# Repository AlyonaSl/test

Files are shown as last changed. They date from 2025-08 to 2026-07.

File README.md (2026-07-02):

# Label roll holder — 3D-printable, parametric

A slim, industrial-looking desk-edge holder for **3 label rolls**.

Two parametric implementations are provided for the same product:

1. **`LabelHolder.scad`** — OpenSCAD model (primary), exports `STL` + `3MF` +
   `STEP`. See **[OpenSCAD model](#openscad-model-labelholderscad)** below.
2. **`src/label_roll_holder.py`** — CadQuery/Python variant (analytic BREP
   `STEP`), documented in the rest of this file.

---

## OpenSCAD model (`LabelHolder.scad`)

Desk-edge clamp whose stand carries the axle at the **centre of its length**, so
the Ø16 mm axle extends to both sides and the 3 rolls sit on **both sides** of
the central stand. Bayonet end-locks. Fully parametric (all dimensions at the
top), independent modules `Parameters() / Stand() / Clamp() / Axle() / Lock() /
Assembly()`.

Styled after the reference sheet: an organic **"wishbone" stand** with a wide
rounded hook-head and a large **leaf-shaped oval** cutout (`_sil2D`/`_oval2D`),
lens-rimmed flanges, smooth domed fixators, and a hidden rear channel rib behind
a flat 2.2 mm front. Previews render in **white matte** (`render_scad.py`,
`turntable_scad.py`).

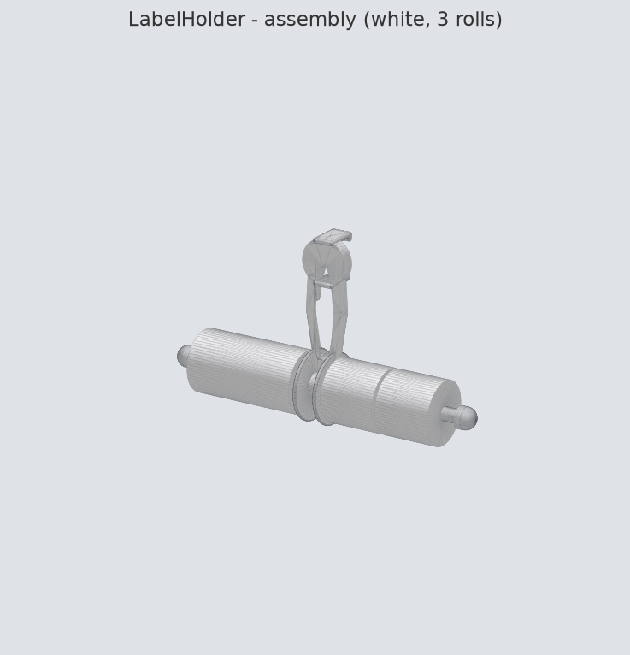
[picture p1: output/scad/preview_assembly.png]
OpenSCAD assembly


### Engineering notes (weak points → fixes)
- **Centre mount halves the cantilever:** supporting the axle at its mid-point
  turns one 290 mm cantilever into two ~145 mm spans. Since δ∝L⁴, the per-side
  deflection at 1.5 kg drops to ≈0.4 mm (PETG) / ≈0.25 mm (PLA) — well within
  "no visible sag". `Parameters()` echoes the computed value.
- **Central roll stops:** two Ø(core_max+4) flanges flank the hub so rolls
  (cores Ø50–80) cannot slide into the stand; the axle passes through a central
  through-bore and is retained by the two bayonet end fixators.
- **Reinforced foot** at the base ties the hub into the blade (no trapped voids,
  stiffest where the bending moment peaks). `axle_dia` stays parametric.
- **Stand bending** (2.2 mm blade is far too soft) → **hidden rear perimeter rib
  (channel section)** adds depth in the load direction; the front stays flat and
  2.2 mm.
- **Clamp spine** locally thickened to full rib depth and blended with large
  radii (no L-bracket).
- Printable without supports (overhangs ≥45°/bridged); recessed screw; bayonet
  for one-hand tool-free removal.

### Parts
| Part | Print qty | Module |
|---|---|---|
| Stand (blade + hidden rib + clamp head + central hub + flanges) | 1 | `Stand()` |
| Clamp thumb-screw (recessed, self-tapping) | 1 | `Clamp()` |
| Axle Ø16 (plain rod, bayonet lug at each end) | 1 | `Axle()` |
| Small domed "pebble" end fixator (Ø26) | 2 | `Lock()` |

> The end fixators are intentionally small for a clean look. They cap/lock the
> axle but do not by themselves stop large (Ø50–80) cores from sliding off; the
> central Ø84 flanges are the primary spool stops. To add a positive end
> roll-stop, set `end_stop_dia` (e.g. `84`) in the parameters.

Files: `output/scad/<part>.stl` (print), `.3mf` (print), `.step` (reference).

### Printing

See **[PRINTING.md](PRINTING.md)** for the ready-to-slice file list, quantities,
orientation, supports and settings. In short: print `stand.3mf`,
`accessories.3mf` (clamp + 2 caps), and the axle as `axle.3mf` (large beds) or
`axle_a.3mf` + `axle_b.3mf` (split halves for standard beds).

### Build / export (OpenSCAD)
Requires system `openscad` + `xvfb` (headless). Preview one part or export all:
```bash
openscad -D 'PART="stand"' -o stand.stl LabelHolder.scad   # single part
./export.sh                                                # all parts -> STL+3MF+STEP
python3 render_scad.py       # preview PNGs
python3 turntable_scad.py    # demo_turntable.mp4
```
`PART` ∈ `assembly | stand | clamp | axle | lock`.

STEP note: OpenSCAD is a mesh modeller, so the `.step` files are **tessellated**
(via OpenCASCADE), not analytic BREP; the screw STEP uses a smooth shaft while
its STL/3MF keep the full printable thread. For an analytic-surface STEP use the
CadQuery variant below.

---

## CadQuery variant (`src/label_roll_holder.py`)

Same product, authored in Python/CadQuery; produces analytic-BREP `STEP`.

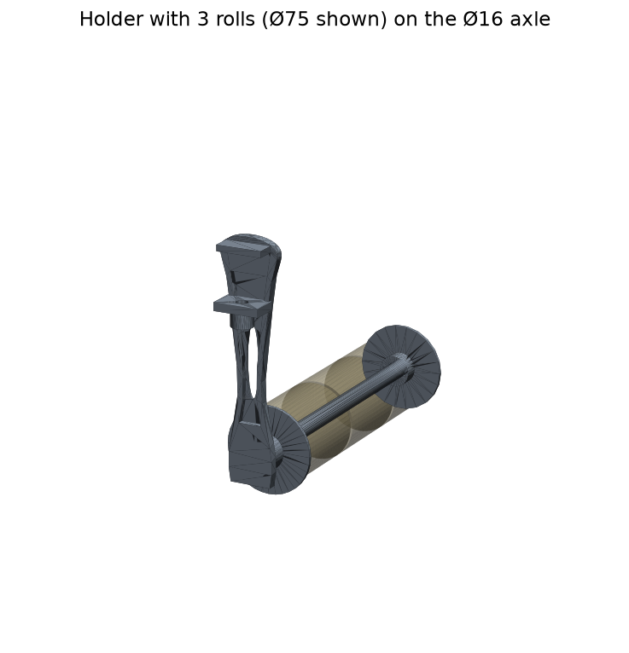
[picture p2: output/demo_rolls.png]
Holder with 3 rolls


## Specification (from the reference)

| Item | Value |
|---|---|
| Rolls | 3, on one axle |
| Roll core inner diameter (втулка) | 50–80 mm |
| Axle (ось) | Ø16 mm, length 286 mm |
| Strut height | 220 mm (56 mm wide at top) |
| Mount | Clamp over the desk edge, desktops 10–40 mm |
| Clamp screw | Printed knurled thumb-screw (tool-free) |
| Axle lock / roll stop | Bayonet fixator (quarter-turn) |

## Parts (in `output/`)

| Part | Print qty | Notes |
|---|---|---|
| `bracket` | 1 | Strut + oval cutout + stiffening rim + edge clamp + axle hub |
| `axle` | 1 | Ø16 mm rod, inner roll-stop flange, bayonet lugs both ends |
| `clamp_screw` | 1 | Knurled thumb-screw, self-taps into the clamp jaw |
| `fixator` | 2 | Bayonet end cap; twist-locks on the axle tip, stops the rolls |

Each part is provided as `.stl` (slice & print) and `.step` (edit in FreeCAD /
Fusion / SolidWorks). `assembly.step` / `assembly.stl` show everything together.

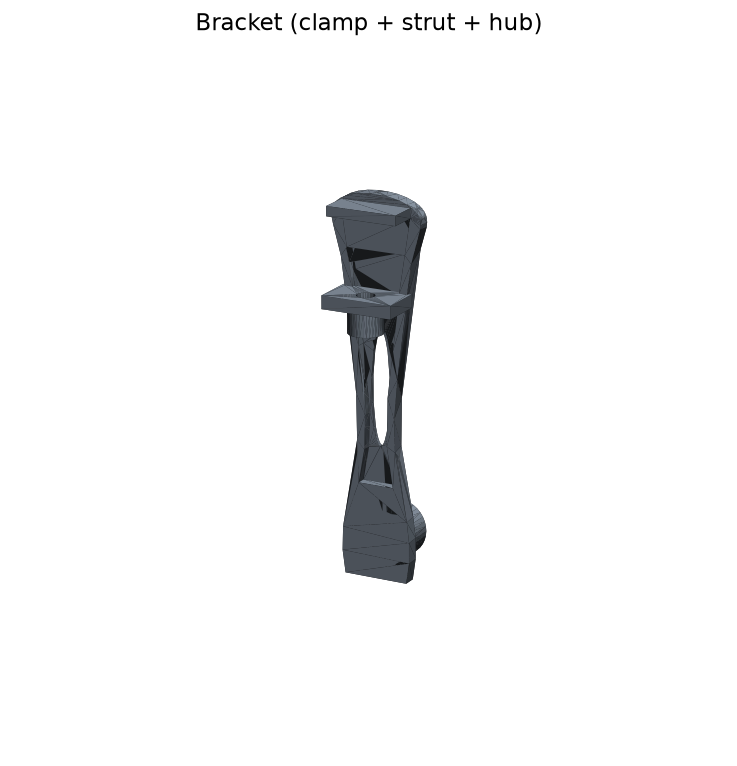
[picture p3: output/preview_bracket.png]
Bracket


## How it goes together

1. Hook the `bracket` over the desk edge; tighten the `clamp_screw` from below
   against the desktop underside (fits 10–40 mm tops).
2. Slide up to 3 rolls onto the `axle` (they rest against the inner flange).
3. Twist a `fixator` onto the axle tip to retain the rolls.
4. Insert the axle inner end into the bracket hub and twist 90° to lock.

## Regenerating the files

Dependencies are in `requirements.txt` (CadQuery + trimesh + matplotlib).

```bash
python3 build.py     # export STL + STEP for every part; validate watertightness
python3 render.py    # per-part preview PNGs
python3 demo.py      # demo_rolls.png + demo_turntable.mp4 (needs ffmpeg)
```

`build.py` exits non-zero if any part is not a watertight, positive-volume
solid — a hard requirement for reliable printing.

## Customising

All dimensions live in the `Spec` dataclass in
[`src/label_roll_holder.py`](src/label_roll_holder.py). Change `num_rolls`,
`axle_len`, `strut_h`, `desk_gap`, etc. and re-run `build.py`.

## Recommended print settings (per the reference sheet)

- **Material:** PLA or PETG.
- **Layer height:** 0.2 mm, **4 perimeters**, **~35 % gyroid** infill.
- **Bracket:** print on its flat back; no supports needed.
- **Clamp screw / fixator:** flat on the bed.
- **Axle:** print upright if the printer is tall enough, otherwise lay it flat.

## Design notes / interpretation

The reference infographic mixes a few inconsistent numbers (e.g. side-view
"110 mm" vs. axle length 286 mm, and core Ø50–80 vs. roll Ø75). This model
follows the explicit part callouts (axle Ø16 × 286 mm; strut 56 × 220 mm; clamp
10–40 mm) and implements a **cantilever axle** with a bayonet mount + a bayonet
end fixator, which is the most functional and print-friendly reading. The clamp
screw self-taps into a plain pilot hole (robust FDM approach) rather than a
modelled internal thread. Everything is parametric, so any of these choices are
one edit away from changing.

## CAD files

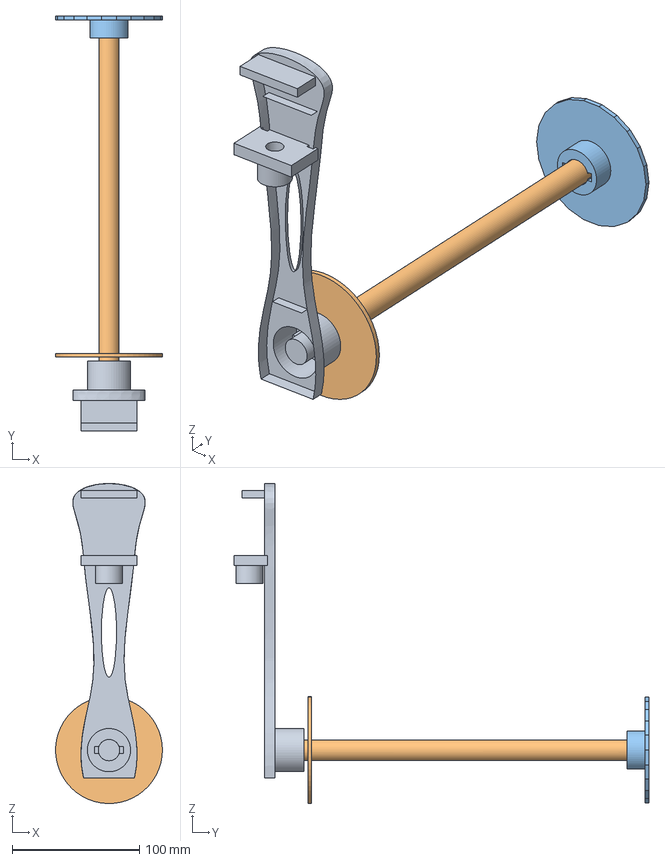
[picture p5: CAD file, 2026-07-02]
output/assembly.step
84.0 x 326.0 x 251.5 mm

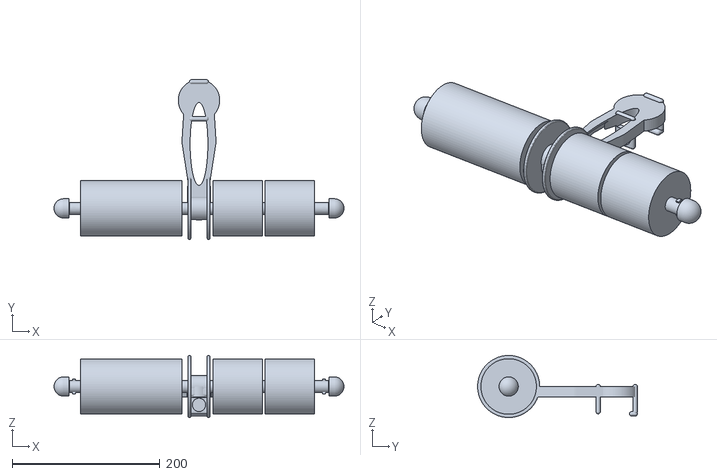
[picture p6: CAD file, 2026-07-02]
output/scad/assembly.stl
392.0 x 216.0 x 84.0

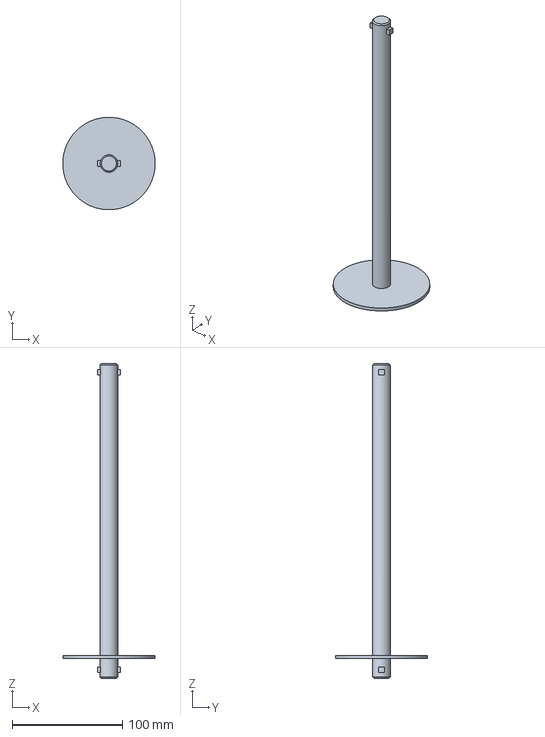
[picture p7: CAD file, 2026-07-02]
output/axle.step
83.9 x 84.0 x 286.0 mm

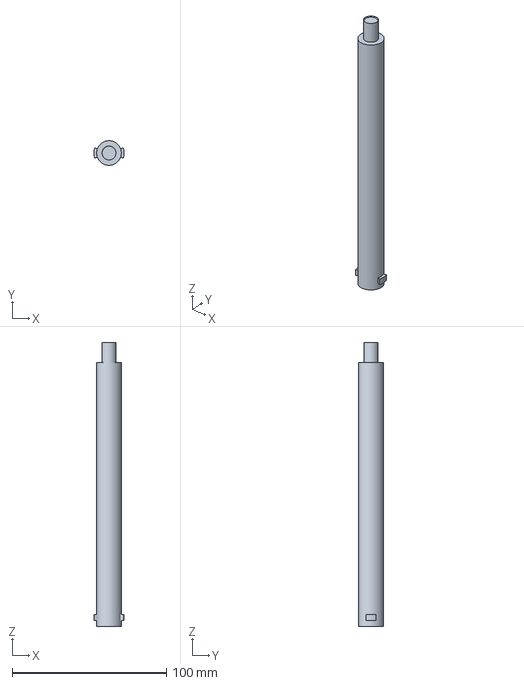
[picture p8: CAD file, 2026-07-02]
output/scad/axle_a.3mf
19.6 x 16.0 x 183.9 mm

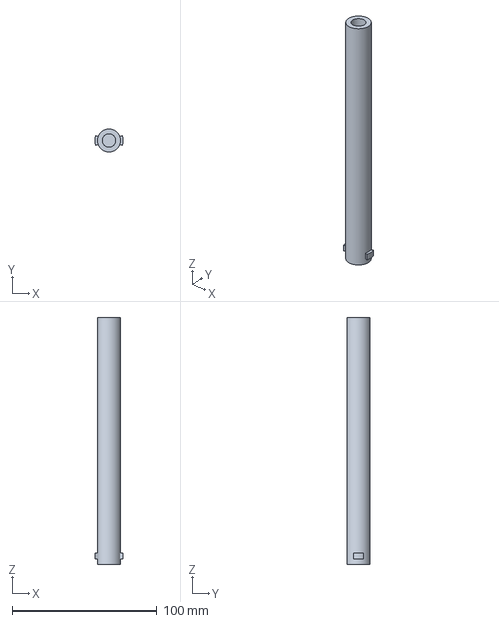
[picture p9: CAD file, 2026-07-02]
output/scad/axle_b.3mf
19.6 x 16.0 x 170.9 mm

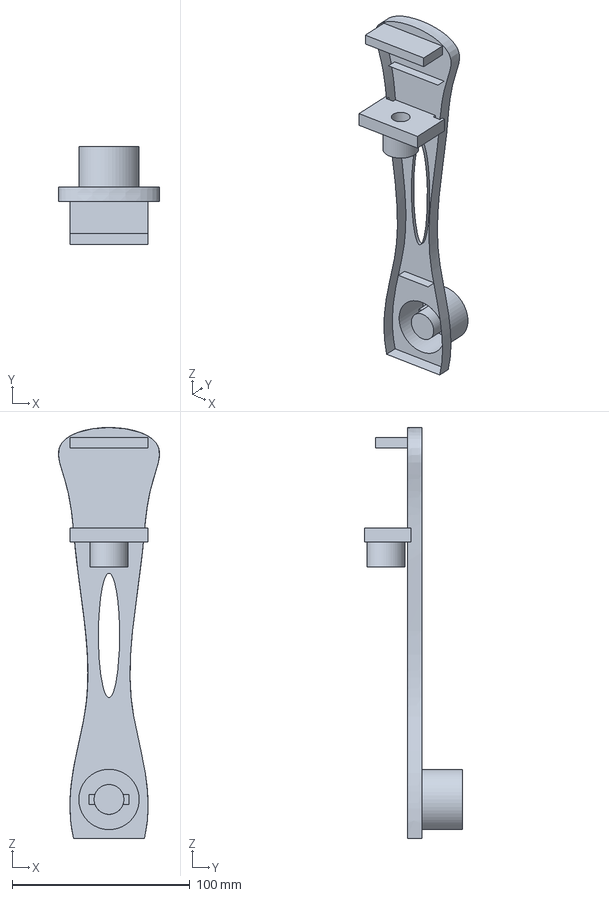
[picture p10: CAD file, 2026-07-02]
output/bracket.step
56.9 x 55.0 x 231.5 mm

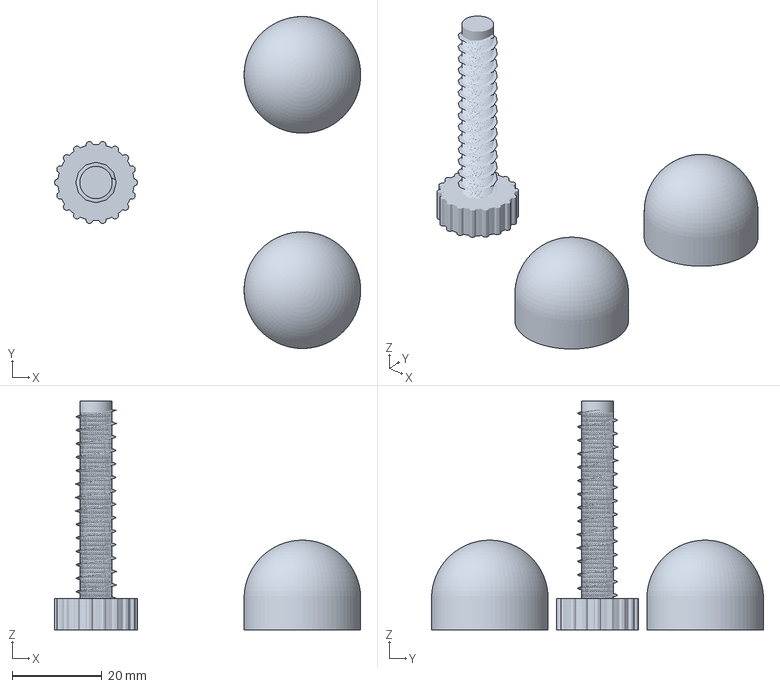
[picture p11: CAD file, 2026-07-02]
output/scad/accessories.3mf
68.3 x 74.0 x 51.0 mm

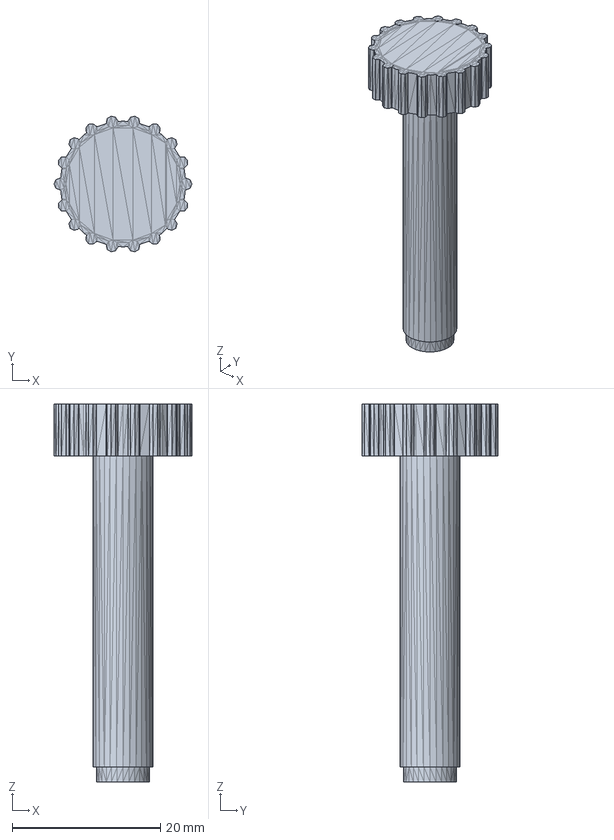
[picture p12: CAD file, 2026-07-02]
output/scad/clamp.step
18.6 x 18.3 x 51.0 mm

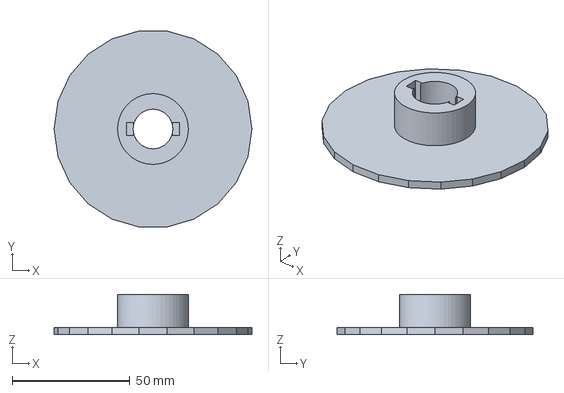
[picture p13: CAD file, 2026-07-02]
output/fixator.step
84.0 x 83.1 x 17.0 mm

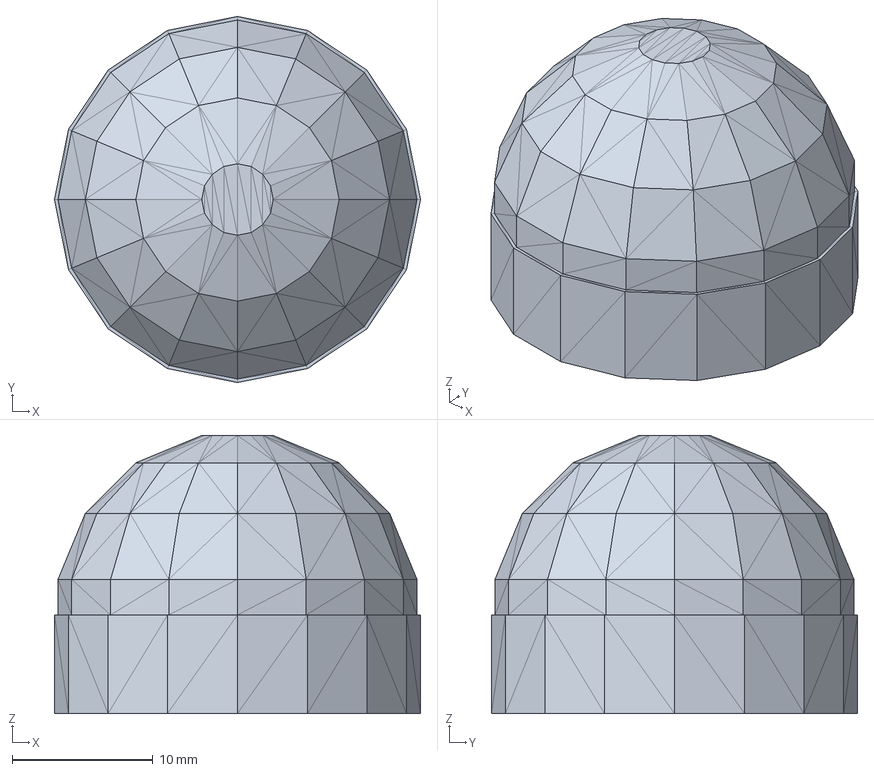
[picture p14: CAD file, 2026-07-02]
output/scad/lock.step
26.0 x 26.0 x 19.8 mm

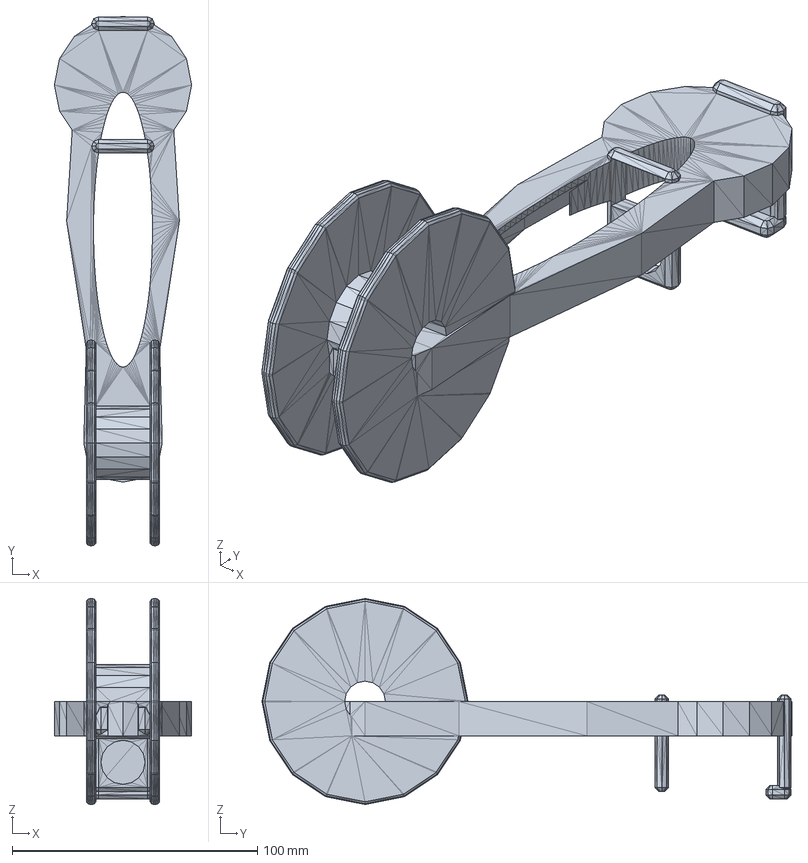
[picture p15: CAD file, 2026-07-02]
output/scad/stand.step
56.0 x 215.9 x 84.0 mm

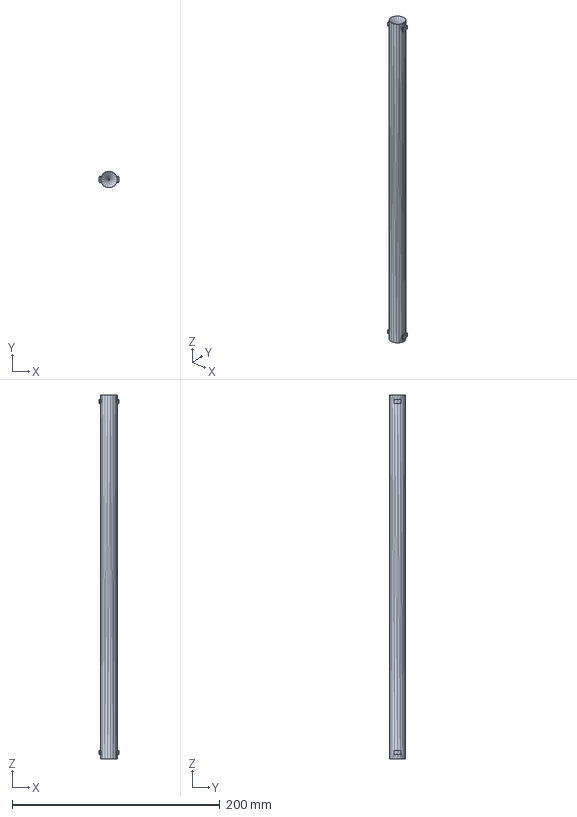
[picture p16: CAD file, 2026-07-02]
output/scad/axle.step
19.6 x 15.8 x 350.3 mm

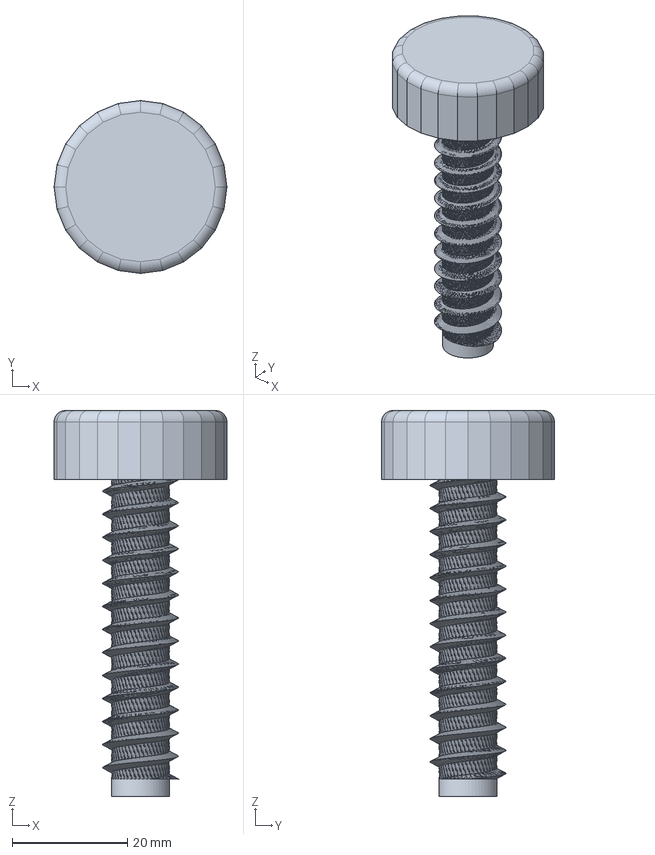
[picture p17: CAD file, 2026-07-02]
output/clamp_screw.step
30.0 x 30.0 x 67.0 mm

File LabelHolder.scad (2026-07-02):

// =============================================================================
//  LabelHolder.scad  —  Compact 3-roll label holder (desk-edge clamp)
//  Parametric, FDM-oriented (PETG / PLA), support-free.
//
//  Frame convention:  X = width, Y = height (0 = bottom .. stand_h = top),
//                     Z = depth (front face at Z = 0, +Z = room/rolls,
//                     -Z = behind = desk side / hidden ribs).
//
//  Printable parts (each independent, print separately):
//     Stand()  - blade + hidden rear rib + edge clamp head + axle hub  (x1)
//     Clamp()  - recessed knurled clamp thumb-screw                    (x1)
//     Axle()   - Ø16 axle, inner roll-stop flange, bayonet ends        (x1)
//     Lock()   - bayonet end fixator / roll stop                       (x2)
//
//  Select what to render/export with the PART variable (see bottom), e.g.:
//     openscad -D 'PART="stand"' -o stand.stl LabelHolder.scad
// =============================================================================

PART = "assembly";   // "assembly" | "stand" | "clamp" | "axle" | "lock"

// -----------------------------------------------------------------------------
//  PARAMETERS  (all dimensions in mm)
// -----------------------------------------------------------------------------

// ---- rolls -------------------------------------------------------
roll_count      = 3;
roll_od_max     = 75;     // max roll outer diameter
core_id_min     = 50;     // min core (втулка) inner diameter
core_id_max     = 80;     // max core inner diameter

// ---- stand (blade) ----------------------------------------------
stand_h         = 220;    // total height
face_t          = 2.2;    // front face plate thickness (stays thin)
stand_w         = 26;     // width at the wide lobes
waist_w         = 18;     // width at the mid waist (gentle taper)

// ---- hidden rear rib (channel stiffener) ------------------------
rib_depth       = 14;     // how far the rib stands off the back
rib_w           = 2.6;    // rib wall thickness

// ---- long oval lightening cutout --------------------------------
oval_len        = 112;    // large leaf-shaped lightening cutout
oval_w          = 24;

// ---- split axle (for smaller print beds) ------------------------
// The 350 mm axle is longer than most beds; print it as two halves that
// join with a centre pin/socket inside the hub. Each half is ~180 mm.
coupler_d       = 9;      // centre coupling pin diameter
coupler_len     = 14;     // pin length / socket depth
coupler_clr     = 0.35;   // pin-in-socket clearance

// ---- axle + CENTRAL hub  (mount is at the CENTRE of the axle) -----
// The stand carries the axle at its mid-point; rolls sit on BOTH sides.
// This turns one 290 mm cantilever into two ~145 mm ones (deflection ~1/16).
axle_dia        = 16;     // spec: Ø16 (raise to reduce deflection)
axle_work       = 290;    // total clear roll span (both sides combined)
axle_end        = 14;     // spare axle past each end lug
bore_clr        = 0.6;    // radial fit clearance (bore vs axle)
hub_od          = 30;     // central hub outer diameter
hub_w           = 26;     // central hub length along the axle (X)
hub_y           = 46;     // axle height above the stand bottom
flange_dia      = core_id_max + 4;  // central roll-stop flanges (> max core)
flange_t        = 4;      // flange thickness (lens rim -> looks thin)

// ---- edge clamp --------------------------------------------------
desk_min        = 10;
desk_max        = 40;
clamp_reach     = 40;     // how far the clamp reaches over/under the desk
clamp_arm_t     = 6;      // hook / jaw thickness (slim)
clamp_open      = 44;     // clear opening (> desk_max) ; screw takes up slack

// ---- clamp screw (recessed, tool-free) --------------------------
screw_dia       = 9;      // major diameter
screw_crest     = 0.9;    // rounded thread crest
screw_pitch     = 3;      // coarse (prints & self-taps well)
screw_len       = 42;
screw_head_dia  = 17;     // knurled head (sits recessed in the jaw)
screw_head_h    = 7;
screw_z         = -clamp_reach*0.62;   // screw position under the desk

// ---- bayonet (compact, so the end caps can be small) -------------
lug_w           = 4;      // lug axial width
lug_h           = 2.2;    // lug radial height
lug_span        = 40;     // lug angular width (deg)
bay_entry       = 7;      // axial entry-slot depth
bay_lock        = 95;     // lock groove sweep (deg)

// ---- lock / fixator (small, elegant domed end knob) -------------
lock_knob_dia   = 26;     // small end-knob diameter (just caps the axle)
lock_knob_h     = 20;     // knob height (houses the compact bayonet socket)
end_stop_dia    = 0;      // 0 = no roll-stop flange (most elegant look).
                          // Set > core (e.g. 84) to positively retain rolls.
end_stop_t      = 3;

// ---- quality -----------------------------------------------------
FN              = 72;     // circle resolution (lower for a light STEP mesh)
screw_slice_mul = 12;     // helical slices per thread turn
THREADED        = true;   // false -> smooth shaft (used for a compact STEP)
$fn             = FN;
eps             = 0.05;

// ---- derived -----------------------------------------------------
each_side   = axle_work/2;                                  // roll span per side
axle_total  = hub_w + 2*flange_t + axle_work + 2*axle_end;  // full axle length
bore_d      = axle_dia + bore_clr;
bot_y       = hub_y;
strut_span  = stand_h - bot_y;
mid_y       = bot_y + 0.5*strut_span;                       // oval / body centre
top_y       = stand_h - stand_w/2;
jaw_top     = stand_h - clamp_arm_t - clamp_open;
clamp_head_w = 56;        // wide rounded head at the clamp (front view)

// -----------------------------------------------------------------------------
//  Parameters()  —  engineering summary (echoed to the console)
// -----------------------------------------------------------------------------
module Parameters() {
    I    = PI*pow(axle_dia,4)/64;                 // 2nd moment of area
    w    = 15/axle_work;                          // 1.5 kg UDL (N/mm)
    // centre mount -> each side is a ~each_side cantilever (balanced load)
    dPET = w*pow(each_side,4)/(8*2100*I);         // PETG per-side deflection
    dPLA = w*pow(each_side,4)/(8*3600*I);         // PLA  per-side deflection
    echo(str("[LabelHolder] axle I = ", round(I), " mm^4"));
    echo(str("[LabelHolder] centre-mount: 2 x ", each_side, " mm spans"));
    echo(str("[LabelHolder] per-side deflection @1.5kg : PETG ~", round(dPET*10)/10,
             " mm, PLA ~", round(dPLA*10)/10, " mm"));
    echo(str("[LabelHolder] axle total length = ", axle_total, " mm"));
}

// -----------------------------------------------------------------------------
//  Small helpers
// -----------------------------------------------------------------------------

// Rounded box (organic, large-radius) via minkowski.
module rbox(sz, r=3) {
    minkowski() {
        cube([max(sz[0]-2*r,0.01), max(sz[1]-2*r,0.01), max(sz[2]-2*r,0.01)],
             center=true);
        sphere(r=r, $fn=max(8, floor(FN/3)));
    }
}

// Disc with a fully rounded rim (elegant "lens" flange), centred on Z.
module rdisc(d, h, r) {
    minkowski() {
        cylinder(d=max(d-2*r, 0.1), h=max(h-2*r, 0.1), center=true);
        sphere(r=r, $fn=max(10, floor(FN/2)));
    }
}

// Smooth spherical-cap dome of base diameter d and height h, base at z=0.
module _dome(d, h) {
    r = d/2;
    scale([1, 1, h/r])
        intersection() {
            sphere(r=r, $fn=FN);
            translate([0, 0, 0]) cylinder(r=r, h=r);
        }
}

// 2D blade silhouette: a graceful organic "wishbone" — narrow foot, gentle
// body swell around the oval, wide rounded head at the clamp. Built by hulling
// a chain of control circles for smooth, large-radius transitions.
module _sil2D() {
    k = [
        [bot_y,                        hub_od + 2],   // foot (blends into hub)
        [bot_y + 0.22*strut_span,      30],
        [bot_y + 0.52*strut_span,      46],           // body swell (flanks oval)
        [bot_y + 0.80*strut_span,      40],
        [stand_h - clamp_head_w/2,     clamp_head_w], // rounded head, top=stand_h
    ];
    for (i = [0 : len(k) - 2])
        hull() {
            translate([0, k[i][0]])     circle(d = k[i][1]);
            translate([0, k[i+1][0]])   circle(d = k[i+1][1]);
        }
}

// Large leaf-shaped (elliptical) lightening cutout, centred on the body.
module _oval2D() {
    translate([0, mid_y]) resize([oval_w, oval_len]) circle(d = oval_len, $fn = 120);
}
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

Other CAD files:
output/assembly.stl
output/axle.stl
output/bracket.stl
output/clamp_screw.stl
output/fixator.stl
output/scad/accessories.stl
output/scad/axle.3mf
output/scad/axle.stl
output/scad/axle_a.stl
output/scad/axle_b.stl
output/scad/clamp.3mf
output/scad/clamp.stl
output/scad/lock.3mf
output/scad/lock.stl
output/scad/stand.3mf
output/scad/stand.stl

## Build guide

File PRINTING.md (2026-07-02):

# Printing guide — LabelHolder

Ready-to-slice files are in [`output/scad/`](output/scad/). Use the **`.3mf`**
files (they embed millimetre units and open in Bambu Studio / OrcaSlicer /
PrusaSlicer / Cura); `.stl` is provided as well. `.step` is for CAD editing only,
not for printing.

## What to print (quantities)

| Part | File | Qty |
|---|---|---|
| Stand (wishbone bracket) | `stand.3mf` | 1 |
| Clamp thumb-screw + 2 end caps (one small plate) | `accessories.3mf` | 1 |

…plus the **axle**, choose ONE option depending on your bed size:

| Bed size | Axle files | Qty |
|---|---|---|
| **≥ 360 mm** (or ~256 mm printed diagonally) | `axle.3mf` (one piece, ~350 mm) | 1 |
| **Standard (≤ 300 mm)** — recommended | `axle_a.3mf` + `axle_b.3mf` (two halves) | 1 each |

The two axle halves join with a **centre pin/socket** that seats inside the hub,
so the split is invisible in use and needs no glue (add a drop of glue if you
want it permanent).

> Why: the one-piece axle is ~350 mm — longer than most FDM beds. The split
> halves are ~180 mm and fit any common printer.

## Orientation & supports (print without supports)

- **accessories.3mf** — already laid out: screw **head-down**, caps **dome-up**.
  No supports.
- **axle / axle_a / axle_b** — lay the rod **flat/horizontal** on the bed; add a
  **brim** for adhesion. No supports.
- **stand.3mf** — print on its **back** (flat face up, rear ribs on the bed).
  No supports needed for the blade, oval or hook thanks to the ≥45° geometry; if
  your slicer flags the clamp jaw underside, enable minimal/tree supports there
  only.

## Recommended slicer settings (from the design sheet)

- Material: **PETG** (preferred for the 1.5 kg load) or **PLA**
- Layer height: **0.2 mm**
- Walls / perimeters: **4**
- Infill: **~35 % gyroid**
- Supports: **off** (see stand note above)
- Colour: white matte looks best (any colour works)

## Assembly

1. Hook the **stand** over the desk edge; tighten the **clamp screw** from
   below until snug (tool-free knurled head; fits 10–40 mm desktops).
2. Load rolls onto the axle. For the split axle: put rolls on each half, then
   push the halves together (pin → socket) through the central hub. For the
   one-piece axle: slide it through the hub and add rolls on both sides.
3. Twist a **pebble end cap** onto each axle end (bayonet, 90°).

## Re-generating the files

Edit parameters at the top of [`LabelHolder.scad`](LabelHolder.scad) and run
`./export.sh` (needs `openscad` + `xvfb`). Useful parameters:

- `end_stop_dia` — set to `84` to add a positive roll-retention flange to the
  end caps (default `0` = small elegant caps).
- `axle_work`, `roll_od_max`, `core_id_max` — size to your rolls.

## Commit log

2026-07-02 Add parametric CadQuery model for 3-roll label holder
    Generates printable STL + editable STEP files for a desk-side-mounted
    holder for 3 label rolls (width <=50mm, core ID 50-80mm). Includes a
    build/validation script (watertightness check) and a headless preview
    renderer, plus project docs and env setup notes.
2026-07-02 Add generated printable files (STL/STEP) and preview renders
    [assembly.step, assembly.stl, bracket.step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]
2026-07-02 Redesign holder to match reference sheet: edge-clamp bracket + bayonet axle
    Reworks the model into the 'elegant centre-mount' design from the provided
    product sheet:
    - bracket: tapering strut with oval lightening cutout, stiffening rim,
    reinforced foot, over-edge clamp (self-tapping printed screw), axle hub
    - axle: Ø16x286 rod with inner roll-stop flange and bayonet lugs
    - clamp_screw: printed knurled thumb-screw (robust twistExtrude thread)
    - fixator (x2): bayonet end cap / roll stop
    Adds demo.py (3-roll demo render + turntable) and updates docs.
2026-07-02 Regenerate printable files (STL/STEP), previews, and demo artifacts
    [assembly.step, assembly.stl, axle.step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]
2026-07-02 Add parametric OpenSCAD model (LabelHolder.scad) + export pipeline
    Full engineering-driven OpenSCAD implementation per spec:
    - Parameters/Stand/Clamp/Axle/Lock/Assembly modules, all dimensions at top
    - elegant thin (2.2mm) tapering blade, long oval cutout, big radii
    - hidden rear perimeter rib (channel) as the main stiffener; front stays flat
    - desk-edge clamp with recessed self-tapping thumb-screw (no L-bracket)
    - Ø16 axle, deep 30mm hub, integral roll-stop flange, one-hand bayonet lock
    - support-free (>=45deg), prints as separate parts
    - Parameters() echoes axle deflection estimate
    Adds export.sh (STL+3MF+STEP), step_export.py (OCP tessellated STEP),
    render_scad.py + turntable_scad.py pre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
    [LabelHolder.scad]
2026-07-02 Add OpenSCAD exports: STL + 3MF + STEP per part, previews, turntable
    [assembly.stl, axle.3mf, axle.step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]
2026-07-02 Move mount to the CENTRE of the axle (rolls on both sides)
    Per feedback: the stand now carries the axle at its mid-point instead of
    cantilevering from one end.
    - central through-hub (axis along the axle) with two roll-stop flanges
    - axle is a plain Ø16 rod through the hub, bayonet lug at each end
    - two bayonet fixators (one per end) retain the rolls
    - reinforced solid foot ties hub into the blade (removes a trapped void)
    Centre support turns one 290mm cantilever into two ~145mm spans, cutting
    per-side deflection from ~6.6mm to ~0.4mm (PETG) at 1.5kg.
    [LabelHolder.scad]
2026-07-02 Regenerate center-mount exports (STL/3MF/STEP), previews, turntable
    [assembly.stl, axle.3mf, axle.step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]
2026-07-02 Refine aesthetics: lens-rim flanges, domed fixators, softer clamp, slim oval
    - central roll-stop flanges and lock flange now have fully rounded (lens) rims
    - end fixators are smooth spherical-cap domes (was fluted cylinder)
    - clamp hook/jaw blended with larger radii; slimmer arms
    - longer, thinner oval cutout
    - shape-helper facet counts now scale with FN (keeps coarse STEP compact)
    [LabelHolder.scad]
2026-07-02 Regenerate refined exports (STL/3MF/STEP), previews, turntable
    [assembly.stl, axle.3mf, axle.step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]
2026-07-02 Match reference look: organic wishbone stand + leaf oval, white matte renders
    - reworked _sil2D into a graceful wishbone (rounded hook-head, body swell,
    narrow foot) and _oval2D into a large leaf-shaped elliptical cutout
    - previews and turntable now render in white matte on a light backdrop
    (as on the reference product sheet)
    [LabelHolder.scad]
2026-07-02 Regenerate reference-style white exports (STL/3MF/STEP), previews, turntable
    [assembly.stl, axle.3mf, axle.step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]
2026-07-02 Make end fixators small elegant domed pebbles (Ø26)
    - Lock is now a small smooth domed knob that caps/locks the axle end via a
    compact bayonet (was a big Ø84 domed disc), for a much cleaner look
    - optional roll-stop flange via new end_stop_dia parameter (0 = off/elegant;
    set > core, e.g. 84, for positive retention of large cores)
    - compact bayonet (smaller lugs/entry) so the caps can be small
    [LabelHolder.scad]
2026-07-02 Regenerate exports with small end fixators (STL/3MF/STEP), previews, turntable
    [assembly.stl, axle.3mf, axle.step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]
2026-07-02 Add print-ready files: split axle (fits normal beds), accessories plate, guide
    - axle > 350mm won't fit most beds -> add AxleA/AxleB split halves (~180mm)
    joined by a centre pin/socket inside the hub (print for standard beds)
    - add Accessories() plate: clamp screw (head-down) + 2 pebble caps (dome-up)
    on one small bed, ready to slice
    - PRINTING.md: file list, quantities, orientation, supports, settings, assembly
    - export.sh now emits STL+3MF for all printable parts incl. the new ones
    [LabelHolder.scad]
2026-07-02 Add printer files: axle_a/axle_b + accessories (STL/3MF) and previews
    [accessories.3mf, accessories.stl, axle_a.3mf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]
